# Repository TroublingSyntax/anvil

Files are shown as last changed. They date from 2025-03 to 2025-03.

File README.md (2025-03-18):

# anvil
STM32 based microcontroller personal project. Anvil is the first family of MCU's, focusing on simple pinouts and peripherals, only including connection peripherals and MCU hardware features. This repository is for tracking the physical design in KiCad. The board's firmware and other software is found elsewhere, mentioned in the README file.

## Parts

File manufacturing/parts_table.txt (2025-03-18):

 1. 	    Red LED
 2. 	    Yellow LED
 3. 100 Ohm Ferrite Bead
 4. 40 Ohm  Ferrite Bead
 5. 10k     Resistor
 6. 1.5k    Resistor
 7. 100k    Resistor
 8. 1u      Capacitor
 9. 0.1u    Capacitor
10. 22u     Capacitor
11. 10u     Capacitor
12. 0.01u   Capacitor
13. 10p     Capacitor

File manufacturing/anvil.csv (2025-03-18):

Reference | Value | Footprint | Qty
C1,C2,C3 | 100n | Capacitor_SMD:C_0402_1005Metric | 3
C4 | 10u | Capacitor_SMD:C_0603_1608Metric | 1
C5 | 10n | Capacitor_SMD:C_0402_1005Metric | 1
C6,C7 | 1u | Capacitor_SMD:C_0402_1005Metric | 2
C8 | 0.1u | Capacitor_SMD:C_0402_1005Metric | 1
C9,C10 | 10p | Capacitor_SMD:C_0402_1005Metric | 2
C11,C12 | 22u | Capacitor_SMD:C_0805_2012Metric | 2
D1,D2,LED1,LED2 | YELLOW | LED_SMD:LED_0603_1608Metric | 4
D3 | RED | LED_SMD:LED_0603_1608Metric | 1
FB1 | 120R | Inductor_SMD:L_0603_1608Metric | 1
FB2 | 40R | Inductor_SMD:L_0603_1608Metric | 1
J1 | USB_B_Micro | Connector_USB:USB_Micro-B_Wuerth_629105150521 | 1
J2 | HEADER2 | Connector_PinSocket_2.54mm:PinSocket_1x12_P2.54mm_Vertical | 1
J3 | ARM_JTAG_SWD | Connector_ARM_JTAG_SWD:FTSH-105-01-F-DV-P-TR | 1
J4 | HEADER1 | Connector_PinSocket_2.54mm:PinSocket_1x12_P2.54mm_Vertical | 1
J5 | HEADER3 | Connector_PinSocket_2.54mm:PinSocket_1x10_P2.54mm_Vertical | 1
R1 | 10k | Resistor_SMD:R_0402_1005Metric | 1
R2,R3,R4,R5,R6 | 1k5 | Resistor_SMD:R_0402_1005Metric | 5
R7,R8 | 100k | Resistor_SMD:R_0603_1608Metric | 2
SW2 | SW_SPDT | Button_Switch_SMD:SW_SPDT_PCM12 | 1
SW3 | SW_Push | Button_Switch_THT:SW_PUSH_6mm | 1
U1 | STM32F031C6T6 | Package_QFP:LQFP-48_7x7mm_P0.5mm | 1
U2 | FT232RL | Package_SO:SSOP-28_5.3x10.2mm_P0.65mm | 1
U3 | AMS1117-3.3 | Package_TO_SOT_SMD:SOT-223-3_TabPin2 | 1
Y1 | 16MHz | Crystal:Crystal_SMD_3225-4Pin_3.2x2.5mm | 1

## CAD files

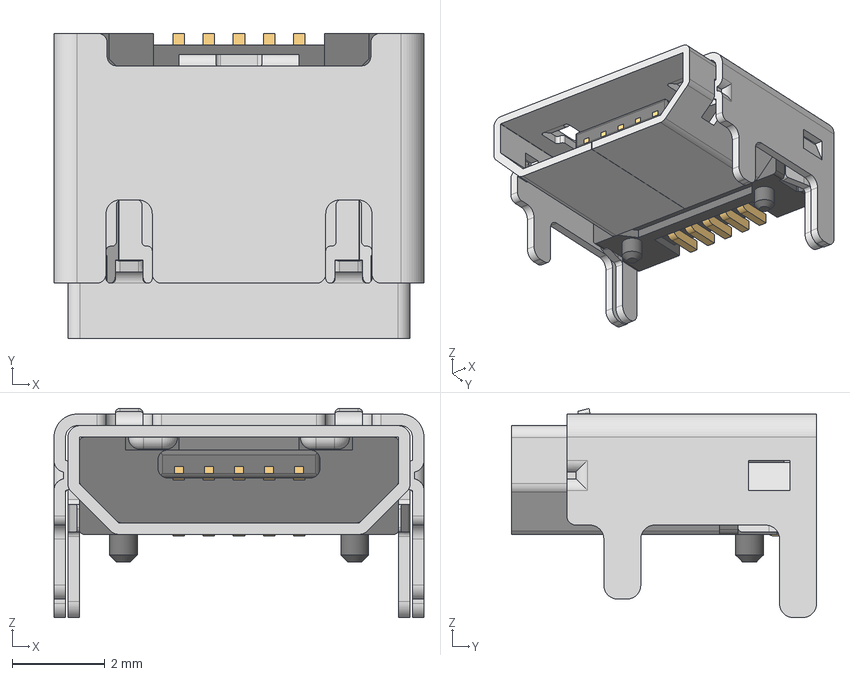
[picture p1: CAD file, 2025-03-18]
629105150521 (rev1).stp
8.00 x 6.60 x 4.52 mm
629105150521_Housing
629105150521_Pin1 x 4
629105150521_Pin2
629105150521_Shielding2
629105150521_Shielding

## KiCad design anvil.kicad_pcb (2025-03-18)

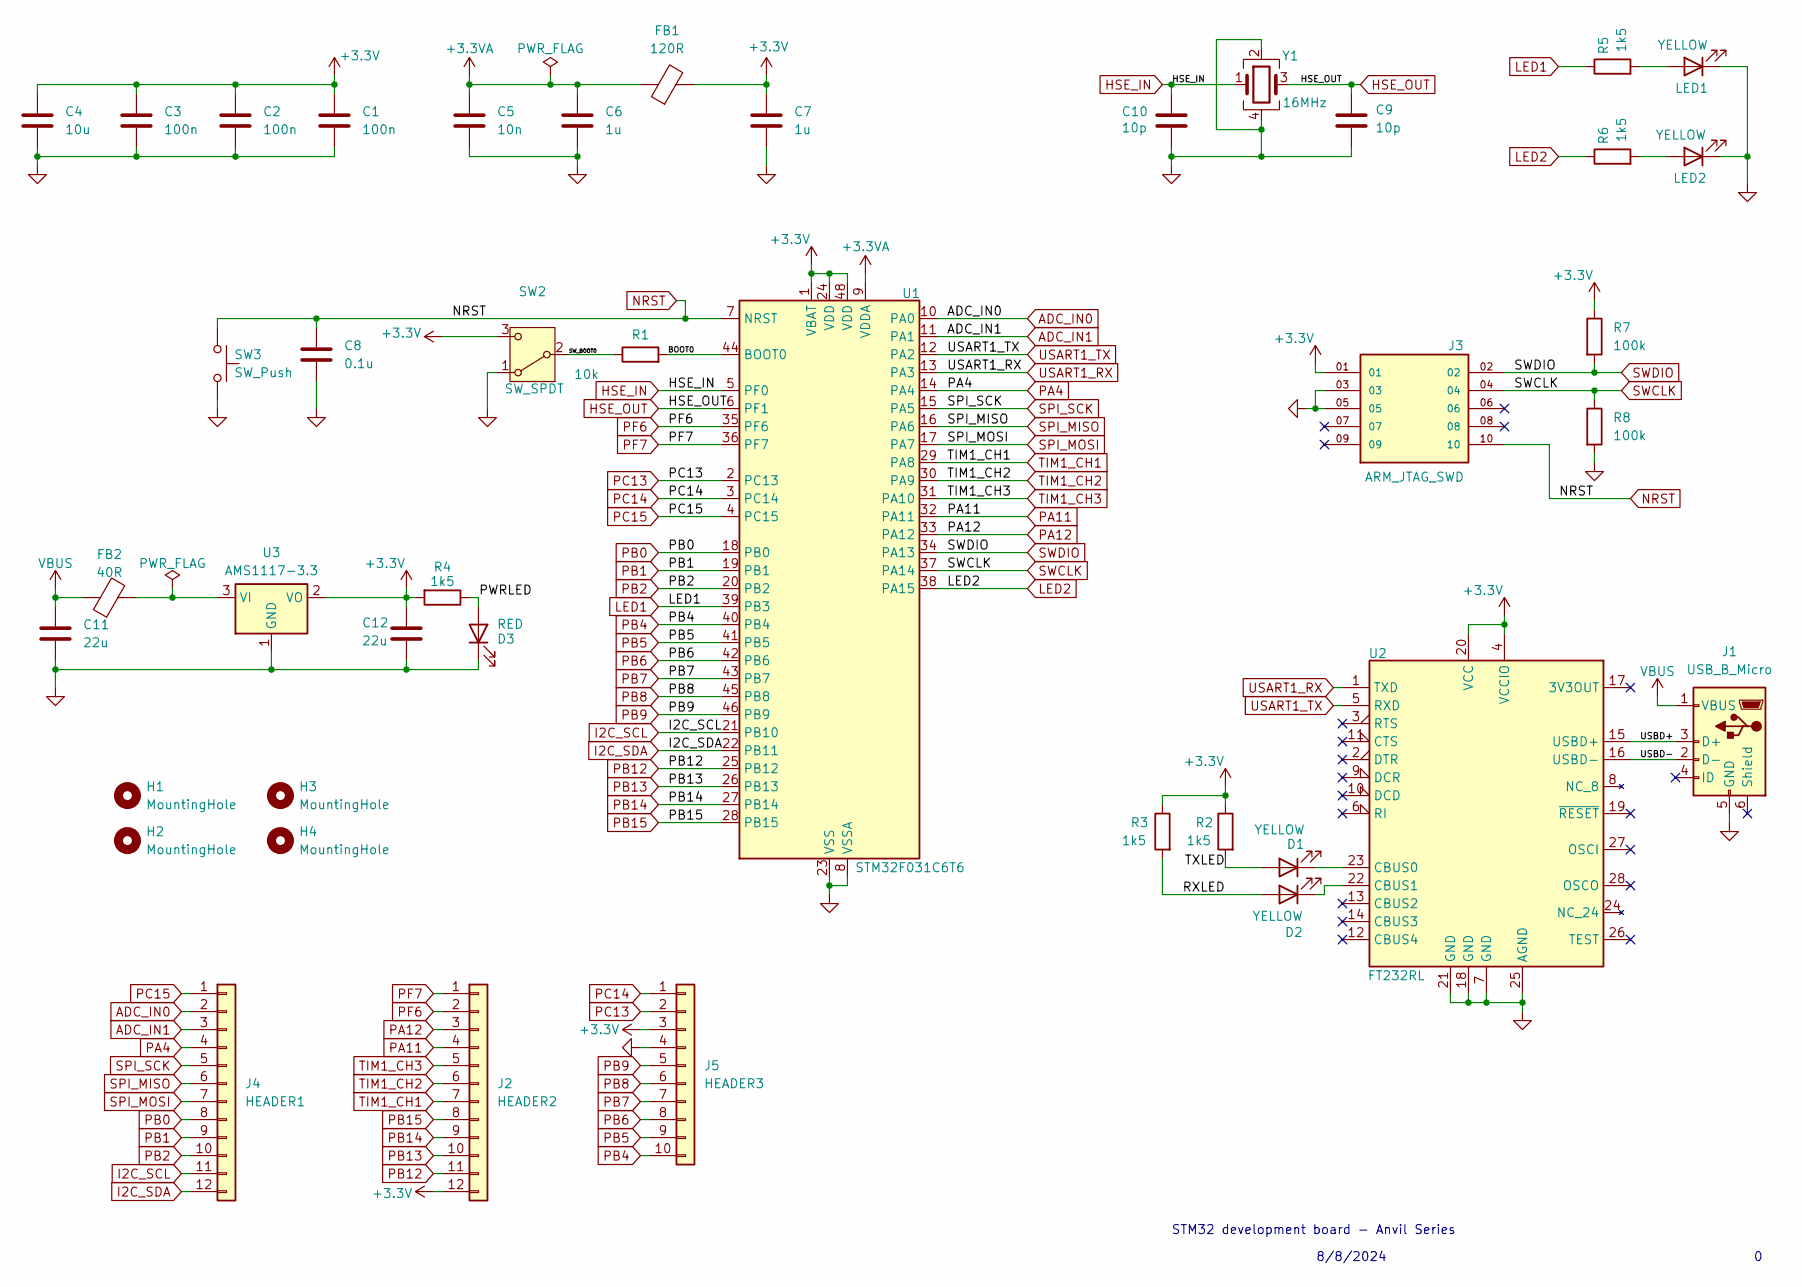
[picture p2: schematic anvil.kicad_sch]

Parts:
C1, C2, C3: 100n; C_0402_1005Metric
C4: 10u; C_0603_1608Metric
C5: 10n; C_0402_1005Metric
C6, C7: 1u; C_0402_1005Metric
C8: 0.1u; C_0402_1005Metric
C9, C10: 10p; C_0402_1005Metric
C11, C12: 22u; C_0805_2012Metric
D1, D2: YELLOW; LED_0603_1608Metric
D3: RED; LED_0603_1608Metric
FB1: 120R; L_0603_1608Metric
FB2: 40R; L_0603_1608Metric
H1, H2, H3, H4: MountingHole; MountingHole_2.2mm_M2
J1: USB_B_Micro; USB_Micro-B_Wuerth_629105150521
J2: HEADER2; PinSocket_1x12_P2.54mm_Vertical
J3: ARM_JTAG_SWD; FTSH-105-01-F-DV-P-TR; PARTREV R
J4: HEADER1; PinSocket_1x12_P2.54mm_Vertical
J5: HEADER3; PinSocket_1x10_P2.54mm_Vertical
LED1, LED2: YELLOW; LED_0603_1608Metric
R1: 10k; R_0402_1005Metric
R2, R3, R4, R5, R6: 1k5; R_0402_1005Metric
R7, R8: 100k; R_0603_1608Metric
SW2: SW_SPDT; SW_SPDT_PCM12
SW3: SW_Push; SW_PUSH_6mm
U1: STM32F031C6T6; LQFP-48_7x7mm_P0.5mm
U2: FT232RL; SSOP-28_5.3x10.2mm_P0.65mm
U3: AMS1117-3.3; SOT-223-3_TabPin2
Y1: 16MHz; Crystal_SMD_3225-4Pin_3.2x2.5mm

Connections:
+3.3V: C1.1, C2.1, C3.1, C4.1, C7.1, C12.1, FB1.2, J2.12, J3.01, J5.3, R2.1, R3.1, R4.2, R7.1, SW2.3 (C), U1.1 (VBAT), U1.24 (VDD), U1.48 (VDD), U2.4 (VCCIO), U2.20 (VCC), U3.2 (VO)
+3.3VA: C5.1, C6.1, FB1.1, U1.9 (VDDA)
/BOOT0: R1.2, U1.44 (BOOT0)
/PWRLED: D3.2 (A), R4.1
/RXLED: D2.2 (A), R3.2
/SW_BOOT0: R1.1, SW2.2 (B)
/TXLED: D1.2 (A), R2.2
/USBD+: J1.3 (D+), U2.15 (USBD+)
/USBD-: J1.2 (D-), U2.16 (USBD-)
ADC_IN0: J4.2, U1.10 (PA0)
ADC_IN1: J4.3, U1.11 (PA1)
GND: C1.2, C2.2, C3.2, C4.2, C5.2, C6.2, C7.2, C8.2, C9.2, C10.2, C11.2, C12.2, D3.1 (K), J1.5 (GND), J3.03, J3.05, J5.4, LED1.1 (K), LED2.1 (K), R8.2, SW2.1 (A), SW3.2, U1.8 (VSSA), U1.23 (VSS), U1.47 (VSS), U2.7 (GND), U2.18 (GND), U2.21 (GND), U2.25 (AGND), U3.1 (GND), Y1.2, Y1.4
HSE_IN: C10.1, U1.5 (PF0), Y1.1
HSE_OUT: C9.1, U1.6 (PF1), Y1.3
I2C_SCL: J4.11, U1.21 (PB10)
I2C_SDA: J4.12, U1.22 (PB11)
LED1: R5.1, U1.39 (PB3)
LED2: R6.1, U1.38 (PA15)
NRST: C8.1, J3.10, SW3.1, U1.7 (NRST)
unnamed: D1.1 (K), U2.23 (CBUS0)
unnamed: D2.1 (K), U2.22 (CBUS1)
unnamed: LED1.2 (A), R5.2
unnamed: LED2.2 (A), R6.2
unnamed: FB2.2, U3.3 (VI)
PA4: J4.4, U1.14 (PA4)
PA11: J2.4, U1.32 (PA11)
PA12: J2.3, U1.33 (PA12)
PB0: J4.8, U1.18 (PB0)
PB1: J4.9, U1.19 (PB1)
PB2: J4.10, U1.20 (PB2)
PB4: J5.10, U1.40 (PB4)
PB5: J5.9, U1.41 (PB5)
PB6: J5.8, U1.42 (PB6)
PB7: J5.7, U1.43 (PB7)
PB8: J5.6, U1.45 (PB8)
PB9: J5.5, U1.46 (PB9)
PB12: J2.11, U1.25 (PB12)
PB13: J2.10, U1.26 (PB13)
PB14: J2.9, U1.27 (PB14)
PB15: J2.8, U1.28 (PB15)
PC13: J5.2, U1.2 (PC13)
PC14: J5.1, U1.3 (PC14)
PC15: J4.1, U1.4 (PC15)
PF6: J2.2, U1.35 (PF6)
PF7: J2.1, U1.36 (PF7)
SPI_MISO: J4.6, U1.16 (PA6)
SPI_MOSI: J4.7, U1.17 (PA7)
SPI_SCK: J4.5, U1.15 (PA5)
SWCLK: J3.04, R8.1, U1.37 (PA14)
SWDIO: J3.02, R7.2, U1.34 (PA13)
TIM1_CH1: J2.7, U1.29 (PA8)
TIM1_CH2: J2.6, U1.30 (PA9)
TIM1_CH3: J2.5, U1.31 (PA10)
USART1_RX: U1.13 (PA3), U2.1 (TXD)
USART1_TX: U1.12 (PA2), U2.5 (RXD)
VBUS: C11.1, FB2.1, J1.1 (VBUS)

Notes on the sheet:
8/8/2024
STM32 development board - Anvil Series

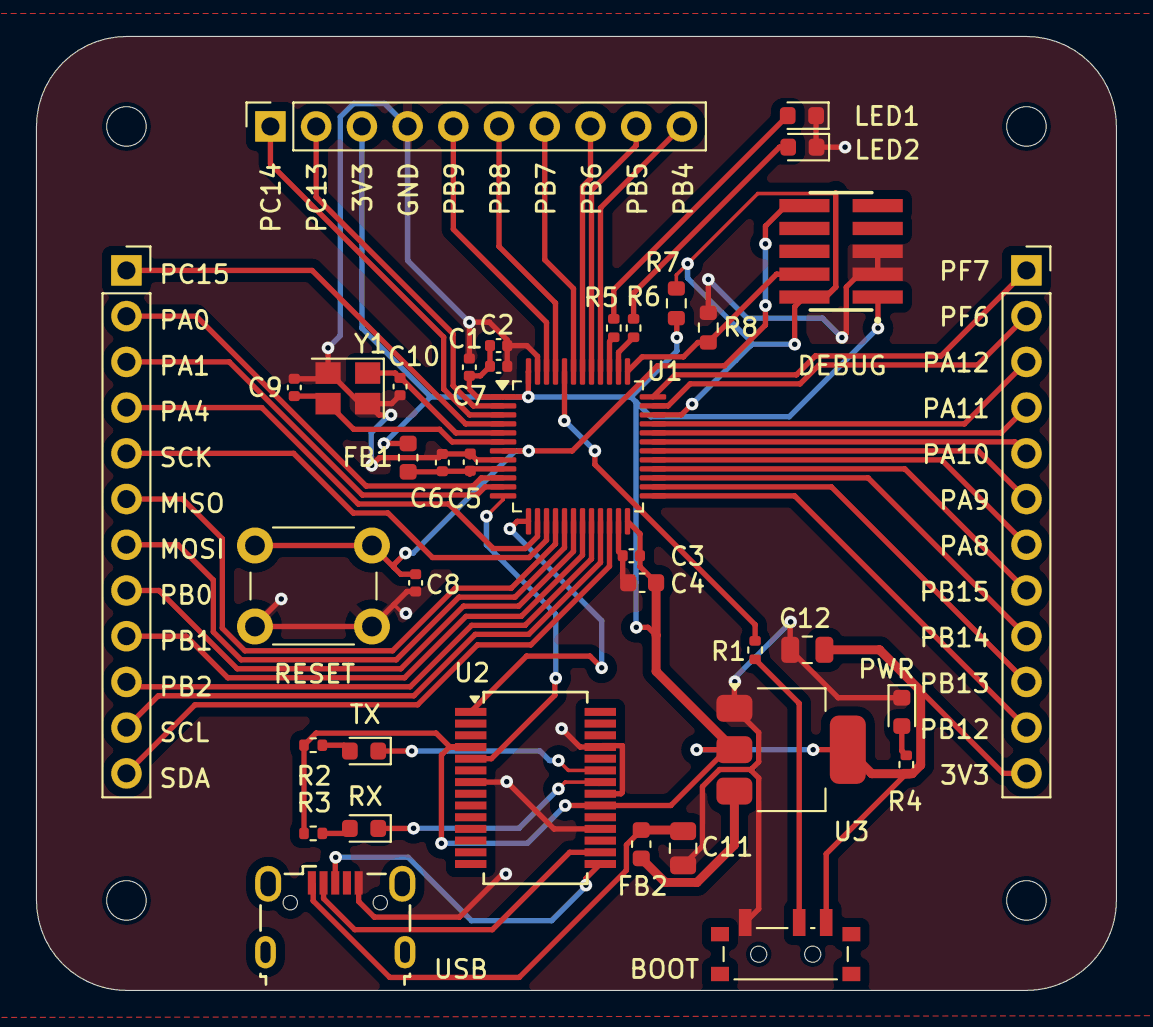
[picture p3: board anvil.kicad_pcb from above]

Board: 2 copper layers, 60.0 x 53.0 mm, 42 parts (0 on the bottom side), 56 nets.

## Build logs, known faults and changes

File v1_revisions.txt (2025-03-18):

Anvil Series v1: Revisions and future version notes

Revisions:
1. USB LED labels
	Issue:    The silk screen labels for "tx" and "rx" are reversed.
	Notes:    Found when using serial terminal, "rx" expected to blink as it was receiving bytes, but "tx" flashed instead.
	Solution: Change the silk screen labels to reflect the real LED functions.
	Status:   Needs to be confirmed in pcb design before changes are made.
2. Boot Switch labels
	Issue:    The silk screen label for "boot" is on the wrong side of the slider swit
	Notes:    Found when trying to upload first LED blink program. When in STM32 Cube IDE, the debugger would start at the default first breakpoint, then when program resumed, it would crash saying it 		  was outside program space in memory. Likely due to address jumping out of program flash memory, as online forums suggested. It was likely entering the boot code because of the switch 			  being reversed, and therefore the program counter pointed to the system memory, wherever the bootloader was located in that memory section.
	Solution: Change the silk screen label to reflect the correct "boot" position.
	Status:	  Needs to be confirmed in pcb design before changes are made.
3. External clock oscillator needs power.
	Issue:    The external clock oscillator smd component is incorrectly connected to the circuit. pin 4, the Vdd pin according to the datasheet, specifies a voltage of +3.3V, however it is 					  currently connected to ground. This is because the tutorial from Phil's Lab on desinging STM32 boards in KiCad used a similar component, but it differed in that sense, because the 				  current connection has pin four grounded instead, as in the Phil's Lab tutorial.
	Notes:	  Once the second revision item regarding the boot selection was addressed and fixed, the program did not fault immediately, but still did not blink. This is because the program went to 			  the clock initialization built-in firmware, and attempted to initialize the external "HSE" clock source. It had a timeout in that firmware, and after using the bugger to narrow down 			  the cause of the issue, it was seen that the issue that caused the program to do nothing was because once the timeout was met for initializing the external clock was met, the firmware 			  would throw an error, which simply points to an infinite while loop that does not display a warning or message of any kind. Once the firmware was reconfigured to use the built-in (and 			  much slower) internal clock oscillator, the program ran as expected for the first time, blinking both LEDs.
	Solution: Likely the solution will involve adding a +3.3V path to pin 4 on the same clock oscillator component that is currently being used in anvil v1. This should be the only necessary change 			  for this issue. It will likely involve some rerouting.
	Status:   This issue was confirmed by testing the original clock oscillator from the prototype board. The testing was done by soldering a few pieces of wire to each pad and connecting pins 2 and 		  4 to ground and +3.3V, respectively, and by connecting HSE_OUT to the input of the oscilloscope. With AC selected and a trigger on rising edge, and with a very small width scale, it 			  was confirmed through selecting frequency as the measurement selection on the oscilloscope that the issue of no oscillator frequency was caused because of the lack of voltage.

Potential Changes or improvements:
1. Add onboard IMU (?)
2. Add SD or MicroSD card (?)
